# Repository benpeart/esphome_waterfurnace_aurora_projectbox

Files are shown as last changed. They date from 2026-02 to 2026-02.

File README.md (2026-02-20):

# Project Box for WaterFurnace Aurora (ESPHome)

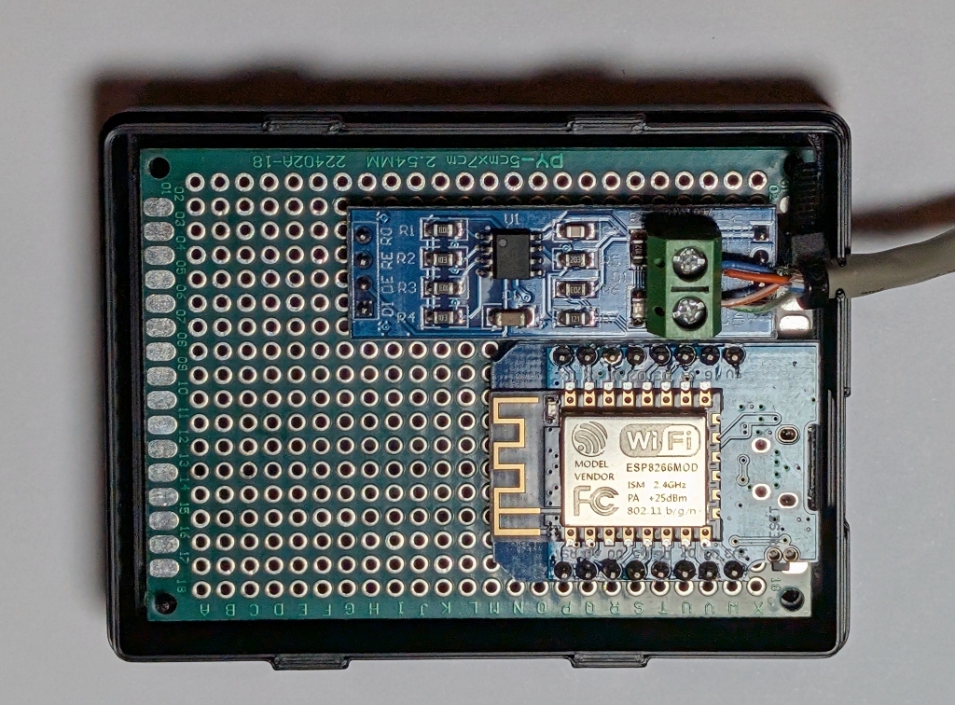
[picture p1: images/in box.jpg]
In Box

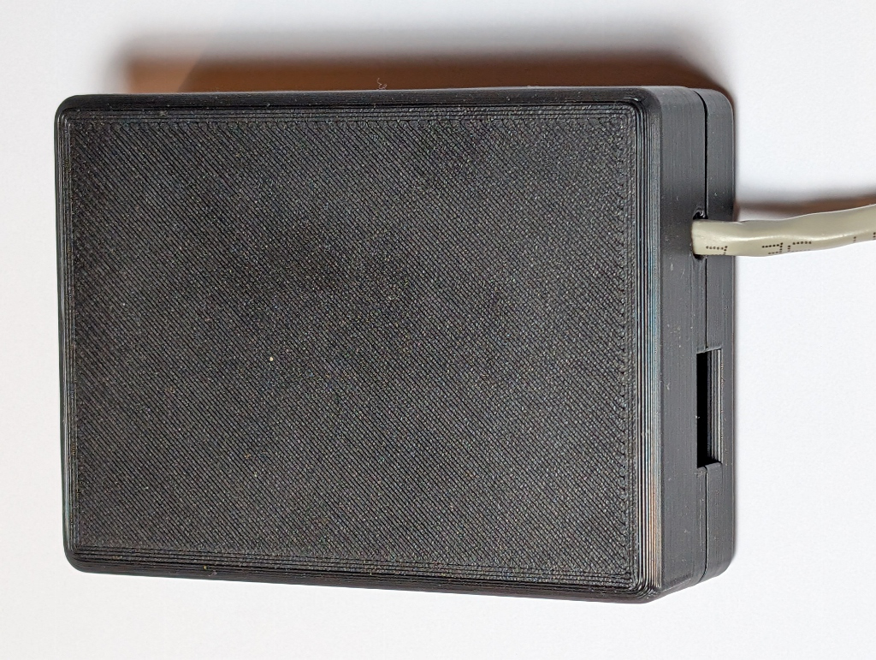
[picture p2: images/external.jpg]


I recently found the amazing project [WaterFurnace Aurora for ESPHome](https://github.com/daemonp/esphome_waterfurnace_aurora). Amazing because I'd seen [WaterFurnace Aurora Gem](https://github.com/ccutrer/waterfurnace_aurora/blob/main/README.md) and was planning on porting it to ESP32 so I could avoid having to setup a docker or Raspberry Pi to get it up and running in my system. Turns out, it had already been done even better than I was planning as it also removed the MQTT requirement (fewer moving parts) and also made it ESPHome compatible (good HW support, simple build/install/upgrade). 

The only thing [WaterFurnace Aurora for ESPHome](https://github.com/daemonp/esphome_waterfurnace_aurora) was missing was good assembly instructions and a nice project box to hold it all in. The goal of this repo is to supply the missing guidance: a simple, reliable project box and a straightforward build process.

## Parts List

| Component | Image |
|---|---|
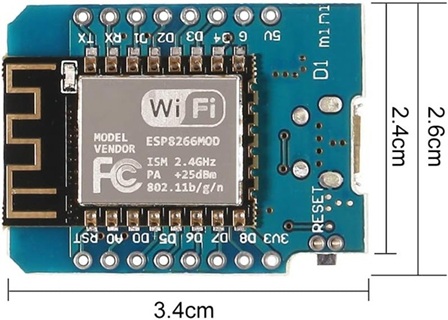
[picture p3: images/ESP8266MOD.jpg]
D1 Mini ESP8266
| D1 Mini ESP8266<br>[Amazon Link](https://www.amazon.com/dp/B08C7FYM5T?th=1) |  |
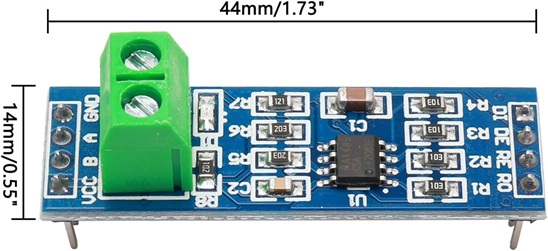
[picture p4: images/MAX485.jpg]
MAX485 Transceiver
| MAX485 Transceiver Module<br>[Amazon Link](https://www.amazon.com/dp/B00NIOLNAG?ref=ppx_yo2ov_dt_b_fed_asin_title) |  |
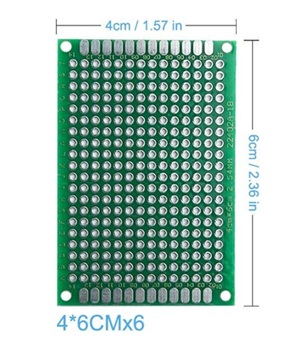
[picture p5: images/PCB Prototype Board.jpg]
PCB Prototype Board
| PCB Prototype Board Kit<br>[Amazon Link](https://www.amazon.com/dp/B072Z7Y19F) |  |
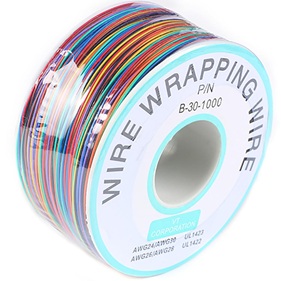
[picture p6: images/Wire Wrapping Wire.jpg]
Wire Wrapping Wire
| 30 AWG Wire Wrapping Wire<br>[Amazon Link](https://www.amazon.com/dp/B0BJ86D1Q3?ref=ppx_yo2ov_dt_b_fed_asin_title) |  |
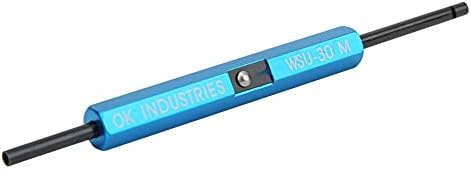
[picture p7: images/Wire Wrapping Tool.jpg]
Wire Wrapping Tool
| 30 AWG Wire Wrapping Tool<br>[Amazon Link](https://www.amazon.com/dp/B0B6GH5HHX?ref=ppx_yo2ov_dt_b_fed_asin_title&th=1) |  |

## Print the Project Box

A ready‑to‑print enclosure is included:

- **STL file:** [projectbox.stl](projectbox.stl)  
- **Source:** [projectbox.scad](projectbox.scad)

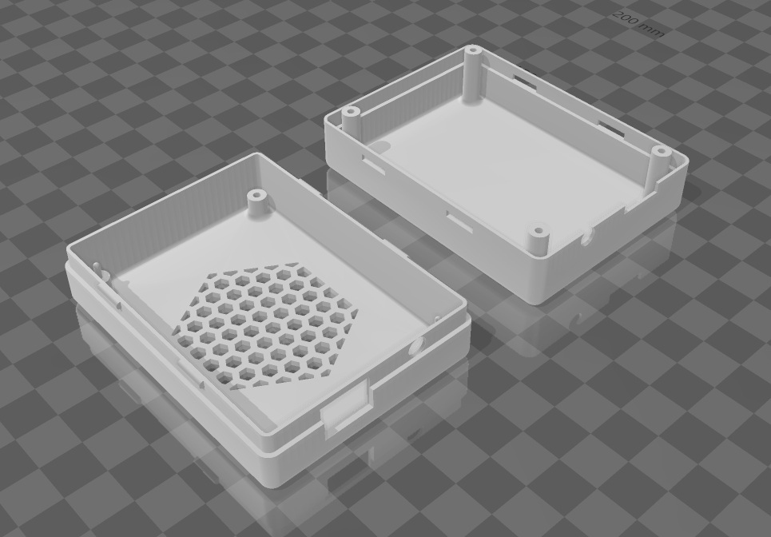
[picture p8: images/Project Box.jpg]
Project Box


The model was created using **[OpenSCAD](https://openscad.org/)** and **[YAPP_Box](https://github.com/mrWheel/YAPP_Box)**, making it easy to customize dimensions or features if needed.

## Create the Cable

You can cut an existing Ethernet patch cable or crimp your own using CAT5/5e.

1. Ensure the RJ45 end is wired to **[TIA-568-B](https://upload.wikimedia.org/wikipedia/commons/6/60/RJ-45_TIA-568B_Left.png)**.  
2. Strip the opposite end and twist the following pairs together:
   - White/Orange + White/Green → **RS485 A / +**
   - Blue + Orange → **RS485 B / ‑**

This matches the WaterFurnace Aurora wiring scheme.

## Assembly Instructions

1. Insert the **D1 Mini** and **MAX485 module** into the prototype PCB.
1. Solder some of the pins to the PCB to hold the parts in place
1. Use 30 AWG wire to wire the ESP8266 to the RS‑485 module.  
1. (Optional) Add a small amount of solder to secure wrapped connections.  
1. Feed the RJ45 cable through the round opening
1. Insert the twisted pairs into the MAX485 screw terminals and tighten.
1. Place the assembled PCB into the printed project box.  
1. Secure the RJ45 cable with a zip‑tie for strain relief.  

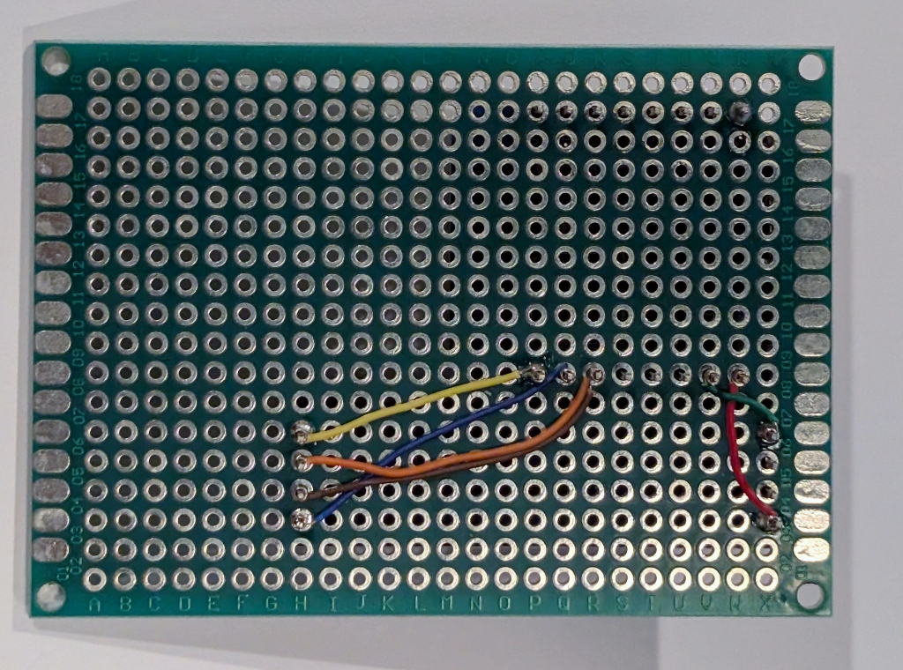
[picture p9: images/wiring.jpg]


### Wiring Reference

| Heat Pump (RJ45) | Wire Color (T568B) | RS485 Module | ESP8266 |
|---|---|---|---|
| Pin 1 (RS485+) | White/Orange | A / + | — |
| Pin 2 (RS485–) | Orange | B / – | — |
| Pin 3 (RS485+) | White/Green | A / + | — |
| Pin 4 (RS485–) | Blue | B / – | — |
| — | — | DI (TX) | TX |
| — | — | RO (RX) | RX |
| — | — | DE/RE | D1 |
| — | — | VCC | 3.3V / 5V |
| — | — | GND | GND |

Once assembled, snap the lid on, connect it to your WaterFurnace system, and your ESPHome Aurora interface is ready to use.

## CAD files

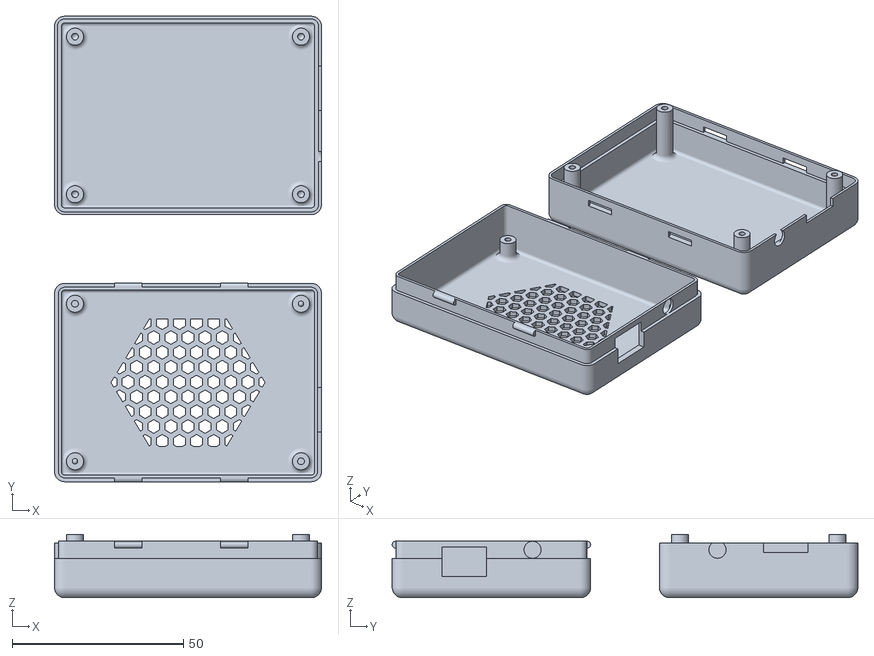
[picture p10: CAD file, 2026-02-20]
projectbox.stl
78.0 x 136.0 x 18.5

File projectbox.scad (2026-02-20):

//-----------------------------------------------------------------------
// Yet Another Parameterized Projectbox generator
//
//  This is a box for WaterFurnace Aurora ESPHome
//
//  Version 3.3.7 (2025-04-17)
//
// This design is parameterized based on the size of a PCB.
//
// For many/complex cutoutGrills, you might need to adjust
//  the max number of elements in OpenSCAD:
//
//      Preferences->Advanced->Turn off rendering at 250000 elements
//                                                   ^^^^^^
//
//-----------------------------------------------------------------------

include <./YAPPgenerator_v3.scad>

//---------------------------------------------------------
// This design is parameterized based on the size of a PCB.
//---------------------------------------------------------
// Note: length/lengte refers to X axis, 
//       width/breedte refers to Y axis,
//       height/hoogte refers to Z axis

/*
      padding-back|<------pcb length --->|<padding-front
                            RIGHT
        0    X-axis ---> 
        +----------------------------------------+   ---
        |                                        |    ^
        |                                        |   padding-right 
      Y |                                        |    v
      | |    -5,y +----------------------+       |   ---              
 B    a |         | 0,y              x,y |       |     ^              F
 A    x |         |                      |       |     |              R
 C    i |         |                      |       |     | pcb width    O
 K    s |         |                      |       |     |              N
        |         | 0,0              x,0 |       |     v              T
      ^ |    -5,0 +----------------------+       |   ---
      | |                                        |    padding-left
      0 +----------------------------------------+   ---
        0    X-as --->
                          LEFT
*/


//-- which part(s) do you want to print?
printBaseShell        = true;
printLidShell         = true;
printSwitchExtenders  = false;
printDisplayClips     = false;

// ********************************************************************
// The Following will be used as the first element in the pbc array

//Defined here so you can define the "Main" PCB using these if wanted
pcbLength           = 70; // front to back (X axis)
pcbWidth            = 50; // side to side (Y axis)
pcbThickness        = 2.0; // at 1.6 there wasn't enough space between the standoffs and the box couldn't close
standoffHeight      = 6.0; //-- How much the PCB needs to be raised from the base to leave room for solderings and whatnot
standoffDiameter    = 5;
standoffPinDiameter = 1.6;
standoffHoleSlack   = 0.4;

//===================================================================
// *** PCBs ***
// Printed Circuit Boards
//-------------------------------------------------------------------
//  Default origin =  yappCoordPCB : yappCoordBoxInside[0,0,0]
//
//  Parameters:
//   Required:
//    p(0) = name
//    p(1) = length
//    p(2) = width
//    p(3) = posx
//    p(4) = posy
//    p(5) = Thickness
//    p(6) = standoff_Height = Height to bottom of PCB from the inside of the base
//             negative measures from inside of the lid to the top of the PCB
//    p(7) = standoff_Diameter
//    p(8) = standoff_PinDiameter
//   Optional:
//    p(9) = standoff_HoleSlack (default to 0.4)

//The following can be used to get PCB values elsewhere in the script - not in pcb definition. 
//If "PCB Name" is omitted then "Main" is used
//  pcbLength           --> pcbLength("PCB Name")
//  pcbWidth            --> pcbWidth("PCB Name")
//  pcbThickness        --> pcbThickness("PCB Name") 
//  standoffHeight      --> standoffHeight("PCB Name") 
//  standoffDiameter    --> standoffDiameter("PCB Name") 
//  standoffPinDiameter --> standoffPinDiameter("PCB Name") 
//  standoffHoleSlack   --> standoffHoleSlack("PCB Name") 

pcb = 
[
  // Default Main PCB - DO NOT REMOVE the "Main" line.
  ["Main", pcbLength, pcbWidth, 0,0, pcbThickness,  standoffHeight, standoffDiameter, standoffPinDiameter, standoffHoleSlack]
];

//-------------------------------------------------------------------                            
//-- padding between pcb and inside wall
paddingFront        = 2;
paddingBack         = 2;
paddingRight        = 2;
paddingLeft         = 2;

//-- Edit these parameters for your own box dimensions
wallThickness       = 2.0;
basePlaneThickness  = 1.5;
lidPlaneThickness   = 1.5;

//-- Total height of box = lidPlaneThickness 
//                       + lidWallHeight 
//--                     + baseWallHeight 
//                       + basePlaneThickness
//-- space between pcb and lidPlane :=
//--      (bottonWallHeight+lidWallHeight) - (standoffHeight+pcbThickness)
baseWallHeight      = 15;
lidWallHeight       = 10;

//-- ridge where base and lid off box can overlap
//-- Make sure this isn't less than lidWallHeight
ridgeHeight         = 5.0;
ridgeSlack          = 0.3; // Gap between the inside of the lid and the outside of the base
//New in v3.3.7 
ridgeGap            = 0.5; // Gap between the bottom of the base ridge and the bottom of the lid when assembled.
roundRadius         = 3.0;

// Box Types are 0-4 with 0 as the default
// 0 = All edges rounded with radius (roundRadius) above
// 1 = All edges sqrtuare
// 2 = All edges chamfered by (roundRadius) above 
// 3 = Square top and bottom edges (the ones that touch the build plate) and rounded vertical edges
// 4 = Square top and bottom edges (the ones that touch the build plate) and chamfered vertical edges
// 5 = Chanfered top and bottom edges (the ones that touch the build plate) and rounded vertical edges
boxType             = 0; // Default type 0

// Set the layer height of your printer
printerLayerHeight  = 0.2;


//---------------------------
//--     C O N T R O L     --
//---------------------------
// -- Render --
renderQuality             = 8;          //-> from 1 to 32, Default = 8

// --Preview --
previewQuality            = 5;          //-> from 1 to 32, Default = 5
showSideBySide            = true;       //-> Default = true
onLidGap                  = 0;  // tip don't override to animate the lid opening
colorLid                  = "YellowGreen";   
alphaLid                  = 1;
colorBase                 = "BurlyWood";
alphaBase                 = 1;
hideLidWalls              = false;      //-> Remove the walls from the lid : only if preview and showSideBySide=true 
hideBaseWalls             = false;      //-> Remove the walls from the base : only if preview and showSideBySide=true  
showOrientation           = true;       //-> Show the Front/Back/Left/Right labels : only in preview
showPCB                   = false;      //-> Show the PCB in red : only in preview 
showSwitches              = false;      //-> Show the switches (for pushbuttons) : only in preview 
showButtonsDepressed      = false;      //-> Should the buttons in the Lid On view be in the pressed position
showOriginCoordBox        = false;      //-> Shows red bars representing the origin for yappCoordBox : only in preview 
showOriginCoordBoxInside  = false;      //-> Shows blue bars representing the origin for yappCoordBoxInside : only in preview 
showOriginCoordPCB        = false;      //-> Shows blue bars representing the origin for yappCoordBoxInside : only in preview 
showMarkersPCB            = false;      //-> Shows black bars corners of the PCB : only in preview 
showMarkersCenter         = false;      //-> Shows magenta bars along the centers of all faces  
inspectX                  = 0;          //-> 0=none (>0 from Back)
inspectY                  = 0;          //-> 0=none (>0 from Right)
inspectZ                  = 0;          //-> 0=none (>0 from Bottom)
inspectXfromBack          = true;       //-> View from the inspection cut foreward
inspectYfromLeft          = true;       //-> View from the inspection cut to the right
inspectZfromBottom        = true;       //-> View from the inspection cut up
//---------------------------
//--     C O N T R O L     --
//---------------------------

//-------------------------------------------------------------------
//-------------------------------------------------------------------
// Start of Debugging config (used if not overridden in template)
// ------------------------------------------------------------------
// ------------------------------------------------------------------
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
